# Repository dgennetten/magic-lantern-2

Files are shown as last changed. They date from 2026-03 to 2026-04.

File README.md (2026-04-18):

# Modular Projection Lantern Generator

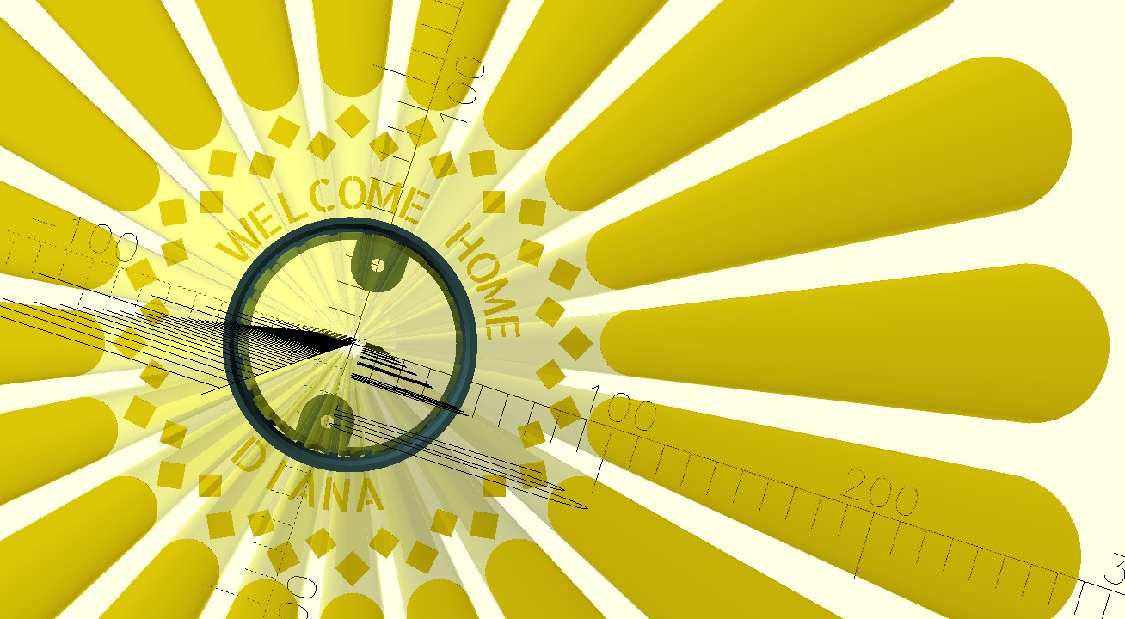
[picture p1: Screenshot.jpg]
CAD illustration


A parametric OpenSCAD project for generating 3D-printable projection lanterns. This generator calculates the precise extrusion angles required to cast undistorted 2D patterns, shapes, and text onto a floor or surface from an elevated point light source.

## OpenSCAD files

| File | Use |
|---|-----|
| **`magicLantern2.scad`** | **Recommended.** Physical settings and render mode at the top; the cutout stack is a single list, `pattern_spec`, built with `layer_*()` helpers. |
| `magicLantern.scad` | Original layout: customize by adding or editing calls inside the `all_2d_patterns()` module. |
| `magicLanternJadeJulian.scad` | Named variant of the original pattern (same `all_2d_patterns()` style). |

Place `AllertaStencil-Regular.ttf` next to whichever `.scad` file you open (see Prerequisites).

## Features

* **Parametric LED mounting:** Adjust variables to friction-fit a LED puck or fixture. Search for “Solar Light Replacement Top 4 Pack (Top Size 3.15 inch, Bottom Size 2.83 inch)” on Amazon as one example.
* **Distortion-corrected projection:** Dynamic scaling keeps patterns farther from the axis visually consistent.
* **Render modes**
  * **`PATTERNS`:** Stack of text, geometry, and rays (in v2, defined in `pattern_spec`).
  * **`SVG`:** Extrude a vector file.
  * **`CAL`:** Shortened body plus a dot spiral to check projection.
* **Mounting tabs** at the base for ceiling or bracket attachment.

## Prerequisites

1. **OpenSCAD:** [openscad.org](https://openscad.org/). For best results, use a recent or nightly build rather than only the 2021 “current” release if you hit quirks.
2. **Allerta Stencil font:** In `PATTERNS` mode, text uses this font so cutouts stay printable (fewer floating islands).
   * Download `AllertaStencil-Regular.ttf` and put it in the same folder as the `.scad` you are editing.
   * The script uses the logical name `"Allerta Stencil"`. Install the font on the system or rely on the local `use <…ttf>` path.

## Quick start

### 1. Configure the light and cylinder

Open **`magicLantern2.scad`** (or your chosen file). Under **Lantern & LED (physical)**, set:

* `light_height` — vertical reference from the bottom of the lantern (floor projection plane, z = 0). Meaning is controlled by `light_height_is_to_rim` (in `magicLantern2.scad` / `magicLantern3.scad`):
  * **`light_height_is_to_rim = false` (default):** `light_height` is floor → **LED emit plane**. The outside rim is `light_height + led_recess`. Changing `led_recess` only deepens the pocket above the LED; projection math uses `light_height` only.
  * **`light_height_is_to_rim = true`:** `light_height` is floor → **outside rim**. The LED emit plane is `light_height - led_recess`, and that value drives projection (`get_floor_r`, taper extrusion, ray preview).
* `cyl_radius`, `wall_thickness` — shell size.
* `led_diameter`, `led_recess`, `tolerance` — friction fit for the puck (`led_recess` = depth of the pocket from the rim toward the LED).

### 2. Choose render mode

Under **What to render on the floor plane**, set `render_mode`:

* `"PATTERNS"` — uses `pattern_spec` (v2) or `all_2d_patterns()` (original files).
* `"SVG"` — set `svg_filename`, `svg_scale`, and offsets.
* `"CAL"` — calibration geometry and shortened cylinder.

### 3. Customize patterns (`magicLantern2.scad`)

Edit the **`pattern_spec`** list: each entry is one `layer_*()` call. Reorder the list to change draw order; duplicate or remove lines to adjust the design.

**Layer builders** (arguments mirror the underlying `project_*` modules):

| Helper | Role |
|---|---|
| `layer_text(distance, msg, …)` | Ring of characters; optional `t_size`, `kerning_deg`, `phase_shift`, `location` (`"top"` / `"bottom"`). |
| `layer_polygon(distance, vertex, …)` | Repeating polygons; optional `rot`, `n`, `duty`, `phase_shift`. |
| `layer_circles(distance, n, …)` | Repeating circles; optional `duty`, `phase_shift`. |
| `layer_rays(distance, bar_h, n, …)` | Wedges; optional `duty`, `phase_shift`. |

**`distance`** — vertical position of the cut on the wall (smaller = closer to the light = projects farther out on the floor).

**`phase_shift`** — ring rotation, in steps of one angular segment: for rays, circles, and polygons it is `phase_shift × (360/n)` degrees. For text it is `phase_shift × kerning_deg`.

The file defines **`_ray_bar_w`** like the original `width_24` helper; use it in `layer_rays(…, bar_h = _ray_bar_w * 4, …)` when you want bar height tied to cylinder arc width.

If you need a new primitive, add a **`layer_*`** function that returns a tagged list, handle it in **`apply_pattern_entry`**, and append to **`pattern_spec`**. The **`project_*`** modules remain the implementation for each shape type.

### 3b. Original files (`magicLantern.scad`, etc.)

In those files, open the **`all_2d_patterns()`** module and add or change **`project_text`**, **`project_polygon`**, **`project_circles`**, and **`project_rays`** calls. Parameters are the same as in the table above, exposed on the `project_*` modules:

**`project_text()`** — Arc centered at **12 o’clock** (top) or **6 o’clock** (bottom) when `phase_shift` is `0`. Two calls with `location = "top"` and `"bottom"` give two opposite arcs.

* **`msg`** — string to project.
* **`t_size`**, **`kerning_deg`**, **`phase_shift`**, **`location`** — as above; **`f_name`** overrides the global font for that ring.

**`project_polygon()`** — **`vertex`** (e.g. `4` for diamonds), **`rot`**, **`n`**, **`duty`**.

**`project_circles()`** — **`n`**, **`duty`**.

**`project_rays()`** — **`bar_h`** (vertical extent of the cut on the wall), **`n`**, **`duty`**.

### 4. Preview and export

1. **F5** — preview.
2. Set **`show_light_rays = false`** before export so visualization geometry is not merged into the mesh.
3. **F6** — full render.
4. **File → Export** as STL (or 3MF).

## Slicing and printing

* **Resolution:** `$fn = 120` for smooth cylinders; high-res meshes work well in slicers such as OrcaSlicer (seam painting along a tab edge can hide the Z-seam).
* **Material:** PLA is fine for tests and `CAL`. If the LED runs warm, PETG reduces long-term warping.
* **Hardware:** Tested on enclosed Core-XY machines (e.g. FlashForge AD5X).
* **Orientation:** Print vertically, LED cavity up; typical pattern cutouts need no supports.

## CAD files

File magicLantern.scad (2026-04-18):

// ==========================================
// MODULAR PROJECTION LANTERN GENERATOR
// ==========================================

// 1. Global Lantern Parameters
light_height = 90;
// Meaning depends on `light_height_is_to_rim` (floor at z = 0)
cyl_radius = 40;
// Outer radius of the lantern cylinder
wall_thickness = 2;      // Thickness of the cylinder wall
font_name = "Allerta Stencil"; 
// Windows default Stencil font
use <AllertaStencil-Regular.ttf>;
$fn = 120;               // Smoothness of 3D curves

// 2. LED Mounting Parameters
led_diameter = 72.5;
// Outer diameter of physical LED light fixture
led_recess = 24;
// Pocket depth from outside rim down toward the LED (how far the emit plane sits below the rim)
tolerance = 0.25;
// Clearance for a snug friction fit

// false: `light_height` = floor → LED (rim = light_height + led_recess). true: `light_height` = floor → rim, LED = light_height - led_recess
light_height_is_to_rim = false;

function projection_led_height() = light_height_is_to_rim ? (light_height - led_recess) : light_height;
function lantern_rim_height() = light_height_is_to_rim ? light_height : (light_height + led_recess);

// 3. Visualization Toggle
show_light_rays = true;
// MUST BE FALSE for final F6 mesh export!

// ==========================================
// 4. RENDER MODE & SVG CONTROLS
// ==========================================
// Select: "PATTERNS", "SVG", or "CAL"
render_mode = "PATTERNS";
svg_filename = "my_pattern.svg"; 
svg_scale = 1.0;         
svg_x_offset = 0;        
svg_y_offset = 0;
// Pre-calculated physical arc widths for the ray cutouts
width_24 = (2 * PI * cyl_radius / 24) * 0.5;
width_12 = (2 * PI * cyl_radius / 12) * 0.5;
// REFACTORED: Calculates floor radius based on distance down from the LED
function get_floor_r(distance) = (projection_led_height() * cyl_radius) / distance;

// ==========================================
// 2D FLOOR PATTERN MODULES
// ==========================================
module project_text(distance, msg, t_size=8, kerning_deg=12, f_name=font_name, phase_shift=0, location="top") {
    floor_r = get_floor_r(distance);
    chars = len(msg);
    total_angle = (chars - 1) * kerning_deg;
    // Half-span so the midpoint between first and last glyph sits at noon (top) or 6 o'clock (bottom).
    start_angle = total_angle / 2;
    bottom = (location == "bottom");
    center_angle = bottom ? 180 : 0;
    // phase_shift=0: arc centered on center_angle. Nonzero: extra rotation in kerning_deg steps.
    angle_offset = kerning_deg * phase_shift;
    for (i = [0 : chars - 1]) {
        a = bottom
            ? (center_angle - start_angle + i * kerning_deg + angle_offset)
            : (center_angle + start_angle - i * kerning_deg + angle_offset);
        rotate(a)
            translate([0, floor_r])
                rotate(bottom ? 180 : 0)
                    text(msg[i], size=t_size, font=f_name, halign="center", valign="center");
    }
}

module project_rays(distance, bar_h, n, duty=0.5, phase_shift=0) {
    // A smaller distance is closer to the light source (higher up the cylinder)
    dist_top = distance - (bar_h / 2);
    dist_bottom = distance + (bar_h / 2);
    
    // The top of the ray projects further out onto the floor than the bottom
    r_outer = get_floor_r(dist_top);
    r_inner = get_floor_r(dist_bottom);
    
    angle_step = 360 / n;
    wedge_angle = angle_step * duty;
    angle_offset = angle_step * phase_shift;
    for (i = [0 : n - 1]) {
        rotate(i * angle_step + angle_offset)
            polygon([
                [ r_inner * tan(wedge_angle/2), r_inner ],
                [ r_outer * tan(wedge_angle/2), r_outer ],
                [-r_outer * tan(wedge_angle/2), r_outer ],
                [-r_inner * tan(wedge_angle/2), r_inner ]
            ]);
    }
}

module project_circles(distance, n, duty=0.5, phase_shift=0) {
    floor_r = get_floor_r(distance);
    angle_step = 360 / n;
    c_r = floor_r * sin((angle_step * duty) / 2);
    angle_offset = angle_step * phase_shift;
    for (i = [0 : n - 1]) {
        rotate(i * angle_step + angle_offset)
            translate([0, floor_r])
                circle(r = c_r);
    }
}

module project_polygon(distance, vertex, rot=0, n=24, duty=0.5, phase_shift=0) {
    floor_r = get_floor_r(distance);
    angle_step = 360 / n;
    p_r = floor_r * sin((angle_step * duty) / 2);
    angle_offset = angle_step * phase_shift;
    for (i = [0 : n - 1]) {
        rotate(i * angle_step + angle_offset)
            translate([0, floor_r])
                // +90 forces 1st vertex to 12 o'clock.
                // -rot applies clockwise offset.
                rotate(90 - rot)
                    circle(r = p_r, $fn = vertex);
    }
}

module project_cal_spiral(start_r=75, end_r=300, dots=37, dot_size=5) {
    // 37 dots guarantees exactly one dot every 10 degrees for a full 360 turn
    for (i = [0 : dots - 1]) {
        angle = i * (360 / (dots - 1));
        floor_r = start_r + i * ((end_r - start_r) / (dots - 1));
        rotate(angle)
            translate([0, floor_r])
                circle(d = dot_size);
    }
}

module all_2d_patterns() {
    if (render_mode == "PATTERNS") {
        // Distances recalculated from 130mm light_height to maintain exact visual placement
        project_text(distance = 65, msg = "WELCOME HOME", t_size = 12, kerning_deg = 12, location = "top");
        project_text(distance = 65, msg = "DIANA", t_size = 12, kerning_deg = 12, location = "bottom");
        // Diamonds (vertex=4, rot=0)
        project_polygon(distance = 44, vertex = 4, rot = 0, n = 20, duty = 0.5);
        // Diamonds (vertex=4, rot=0, phase_shift=.5)
        project_polygon(distance = 49, vertex = 4, rot = 0, n = 20, duty = 0.5, phase_shift = 0.5);
        project_circles(distance = 35, n = 20, duty = 0.75);
        project_rays(distance = 25, bar_h = width_24 * 4, n = 20, duty = 0.75);
        project_circles(distance = 14.5, n = 20, duty = 0.75);

    } else if (render_mode == "SVG") {
        translate([svg_x_offset, svg_y_offset])
            scale([svg_scale, svg_scale])
                import(svg_filename);
    } else if (render_mode == "CAL") {
        project_cal_spiral();
    } else {
        echo("ERROR: render_mode must be 'PATTERNS', 'SVG', or 'CAL'");
    }
}

// ==========================================
// 3D LANTERN COMPONENTS
// ==========================================
module lantern_body() {
    fit_radius = (led_diameter / 2) + tolerance;
    // LED cavity starts slightly below light_height to avoid a coplanar face with the bore (preview/STL).
    merge_eps = 0.05;
    
    led_z = projection_led_height();
    total_height = lantern_rim_height();
    // Auto-shorten the cylinder by 50mm if doing a Calibration print
    cyl_bottom_z = (render_mode == "CAL") ? 50 : 0;

    // Scale math to avoid the tip singularity during extrusion
    extrude_h = led_z - 5;
    extrude_scale = (led_z - extrude_h) / led_z;
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

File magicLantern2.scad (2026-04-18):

// ==========================================
// Modular projection lantern — data-first layout
// Compose cutout layers in pattern_spec (top of file, after a short helper block).
// ==========================================

// ---------------------------------------------------------------------------
// 1. Lantern & LED (physical)
// ---------------------------------------------------------------------------
light_height = 90;           // See `light_height_is_to_rim` below
cyl_radius = 40;
wall_thickness = 2;
//font_name = "Boston Traffic";
//use <boston_traffic.ttf>;
font_name = "Allerta Stencil";
use <AllertaStencil-Regular.ttf>;
$fn = 120;

led_diameter = 72.5;
led_recess = 24;             // Pocket depth from outside rim down toward the LED
tolerance = 0.25;

// How `light_height` is measured (floor at z = 0):
// - false (default): floor → LED emit plane. Rim height = light_height + led_recess. Recess only sizes the lid.
// - true: floor → outside rim. LED emit plane = light_height - led_recess (recess enters projection math).
light_height_is_to_rim = false;

function projection_led_height() = light_height_is_to_rim ? (light_height - led_recess) : light_height;
function lantern_rim_height() = light_height_is_to_rim ? light_height : (light_height + led_recess);

// Mount style: "tabs" (two interior screw tabs) or "flange" (full disc, 1" centre hole)
mount_style = "flange";

// ---------------------------------------------------------------------------
// 2. What to render on the floor plane
//    "PATTERNS" → pattern_spec  |  "SVG" → import  |  "CAL" → calibration spiral
// ---------------------------------------------------------------------------
render_mode = "PATTERNS";
svg_filename = "my_pattern.svg";
svg_scale = 1.0;
svg_x_offset = 0;
svg_y_offset = 0;

// ---------------------------------------------------------------------------
// 3. Declarative layer builders (needed before pattern_spec in OpenSCAD)
// ---------------------------------------------------------------------------
function layer_text(distance, msg, t_size = 8, kerning_deg = 12, phase_shift = 0, location = "top") =
    ["text", distance, msg, t_size, kerning_deg, phase_shift, location];

function layer_rays(distance, bar_h, n, duty = 0.5, phase_shift = 0, count = 0) =
    ["rays", distance, bar_h, n, duty, phase_shift, count];

function layer_circles(distance, n, duty = 0.5, phase_shift = 0, count = 0) =
    ["circles", distance, n, duty, phase_shift, count];

function layer_polygon(distance, vertex, rot = 0, n = 24, duty = 0.5, phase_shift = 0, count = 0) =
    ["polygon", distance, vertex, rot, n, duty, phase_shift, count];

// ---------------------------------------------------------------------------
// 4. Pattern stack — main customization: reorder or edit entries here
// ---------------------------------------------------------------------------
_ray_bar_w = (2 * PI * cyl_radius / 24) * 0.5;

pattern_spec = [
    layer_text(65, "WELCOME HOME", t_size = 12, kerning_deg = 12, location = "top"),
    layer_text(65, "DIANA", t_size = 12, kerning_deg = 12, location = "bottom"),
    layer_polygon(44, vertex = 4, rot = 0, n = 20, duty = 0.5, phase_shift = 0.5),
    layer_polygon(49, vertex = 4, rot = 0, n = 20, duty = 0.5),
    layer_circles(35, n = 20, duty = 0.75, count = 10),
    layer_rays(25, bar_h = _ray_bar_w * 4, n = 20, duty = 0.75, count = 10),
    layer_circles(14.5, n = 20, duty = 0.75, count = 10),
];

// ---------------------------------------------------------------------------
// 5. Preview
// ---------------------------------------------------------------------------
show_light_rays = true;   // set false for F6 export

// ---------------------------------------------------------------------------
// 6. Projection math & 2D primitives
// ---------------------------------------------------------------------------
function get_floor_r(distance) = (projection_led_height() * cyl_radius) / distance;

module project_text(distance, msg, t_size = 8, kerning_deg = 12, f_name = font_name, phase_shift = 0, location = "top") {
    floor_r = get_floor_r(distance);
    chars = len(msg);
    total_angle = (chars - 1) * kerning_deg;
    start_angle = total_angle / 2;
    bottom = (location == "bottom");
    center_angle = bottom ? 180 : 0;
    angle_offset = kerning_deg * phase_shift;
    for (i = [0 : chars - 1]) {
        a = bottom
            ? (center_angle - start_angle + i * kerning_deg + angle_offset)
            : (center_angle + start_angle - i * kerning_deg + angle_offset);
        rotate(a)
            translate([0, floor_r])
                rotate(bottom ? 180 : 0)
                    text(msg[i], size = t_size, font = f_name, halign = "center", valign = "center");
    }
}

module project_rays(distance, bar_h, n, duty = 0.5, phase_shift = 0, count = 0) {
    dist_top = distance - (bar_h / 2);
    dist_bottom = distance + (bar_h / 2);
    r_outer = get_floor_r(dist_top);
    r_inner = get_floor_r(dist_bottom);
    angle_step = 360 / n;
    wedge_angle = angle_step * duty;
    angle_offset = angle_step * phase_shift;
    actual_count = (count > 0 && count <= n) ? count : n;
    rot_sign = (count > 0) ? -1 : 1;
    for (i = [0 : actual_count - 1]) {
        rotate(rot_sign * i * angle_step + angle_offset)
            polygon([
                [ r_inner * tan(wedge_angle / 2), r_inner ],
                [ r_outer * tan(wedge_angle / 2), r_outer ],
                [-r_outer * tan(wedge_angle / 2), r_outer ],
                [-r_inner * tan(wedge_angle / 2), r_inner ]
            ]);
    }
}

module project_circles(distance, n, duty = 0.5, phase_shift = 0, count = 0) {
    floor_r = get_floor_r(distance);
    angle_step = 360 / n;
    c_r = floor_r * sin((angle_step * duty) / 2);
    angle_offset = angle_step * phase_shift;
    actual_count = (count > 0 && count <= n) ? count : n;
    rot_sign = (count > 0) ? -1 : 1;
    for (i = [0 : actual_count - 1]) {
        rotate(rot_sign * i * angle_step + angle_offset)
            translate([0, floor_r])
                circle(r = c_r);
    }
}

module project_polygon(distance, vertex, rot = 0, n = 24, duty = 0.5, phase_shift = 0, count = 0) {
    floor_r = get_floor_r(distance);
    angle_step = 360 / n;
    p_r = floor_r * sin((angle_step * duty) / 2);
    angle_offset = angle_step * phase_shift;
    actual_count = (count > 0 && count <= n) ? count : n;
    rot_sign = (count > 0) ? -1 : 1;
    for (i = [0 : actual_count - 1]) {
        rotate(rot_sign * i * angle_step + angle_offset)
            translate([0, floor_r])
                rotate(90 - rot)
                    circle(r = p_r, $fn = vertex);
    }
}

module project_cal_spiral(start_r = 75, end_r = 300, dots = 37, dot_size = 5) {
    for (i = [0 : dots - 1]) {
        angle = i * (360 / (dots - 1));
        floor_r = start_r + i * ((end_r - start_r) / (dots - 1));
        rotate(angle)
            translate([0, floor_r])
                circle(d = dot_size);
    }
}

module apply_pattern_entry(entry) {
    kind = entry[0];
    if (kind == "text") {
        project_text(
            distance = entry[1],
            msg = entry[2],
            t_size = entry[3],
            kerning_deg = entry[4],
            phase_shift = entry[5],
            location = entry[6]
        );
    } else if (kind == "rays") {
        project_rays(
            distance = entry[1],
            bar_h = entry[2],
            n = entry[3],
            duty = entry[4],
            phase_shift = entry[5],
            count = entry[6]
        );
    } else if (kind == "circles") {
        project_circles(
            distance = entry[1],
            n = entry[2],
            duty = entry[3],
            phase_shift = entry[4],
            count = entry[5]
        );
    } else if (kind == "polygon") {
        project_polygon(
            distance = entry[1],
            vertex = entry[2],
            rot = entry[3],
            n = entry[4],
            duty = entry[5],
            phase_shift = entry[6],
            count = entry[7]
        );
    } else {
        echo("Unknown pattern entry kind: ", kind);
    }
}

module all_2d_patterns() {
    if (render_mode == "PATTERNS") {
        for (entry = pattern_spec)
            apply_pattern_entry(entry);
    } else if (render_mode == "SVG") {
        translate([svg_x_offset, svg_y_offset])
            scale([svg_scale, svg_scale])
                import(svg_filename);
    } else if (render_mode == "CAL") {
        project_cal_spiral();
    } else {
        echo("ERROR: render_mode must be 'PATTERNS', 'SVG', or 'CAL'");
    }
}
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

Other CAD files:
magicLantern3.scad
magicLantern4.scad
magicLanternJadeJulian.scad

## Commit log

2026-03-11 Update magicLantern.scad: Adjusted LED parameters, enabled light ray visualization, and modified render mode to support patterns. Refined lantern body structure for improved LED fitting and extrusion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
    [magicLantern.scad]
2026-03-11 Refactor magicLantern.scad: Enhanced calibration mode functionality, optimized spiral projection rendering, and fine-tuned lantern body dimensions for better assembly and light distribution.
2026-03-12 Refactor magicLantern.scad: Adjusted light height for improved projection accuracy, changed render mode to "PATTERNS", and refactored functions for better parameter handling. Enhanced text projection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
    [magicLantern.scad]
2026-03-12 Refactor magicLantern.scad: Updated font to "Allerta Stencil", enabled light ray visualization, and refined text projection parameters. Adjusted comments for clarity and removed unused SVG file.
    [magicLantern.scad]
2026-03-12 Update README with LED puck link
    Added a link to the LED puck or light source in the features section.
2026-03-12 Update README with LED puck product reference
    Added a specific product reference for LED mounting.
2026-03-21 Remove the unneeded flange
    [magicLantern.scad]
2026-03-21 Cleaned up cylinder interior where previous flange was
    [magicLantern.scad, magicLanternJadeJulian.scad]
2026-03-21 same fix to J&J
    [magicLanternJadeJulian.scad]
2026-03-22 Update light height and adjust text and pattern distances in magicLanternJadeJulian.scad for improved visual placement. Added new facets in magicLanternJadeJulian.stl to enhance model detail.
    [magicLanternJadeJulian.scad]
2026-03-23 Much improved version 2. New "pattern_spec"
    [magicLantern2.scad]
2026-04-08 Refactor magicLanternJadeJulian.scad to enhance text alignment and update pattern specifications for improved visual consistency. Adjusted parameters for better model detail in magicLanternJadeJulian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
2026-04-15 Enhance magicLantern2.scad by introducing a new mount style option ("flange") for improved design flexibility. Updated pattern specifications and refined cylinder construction for better structural i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
    [magicLantern2.scad]
2026-04-15 Refactor magicLantern2.scad to add a 'count' parameter to layer functions and project modules, enhancing control over the number of elements rendered. Updated pattern specifications to utilize the ne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
    [magicLantern2.scad]
2026-04-18 Refactor projection calculations in magicLantern.scad and related files to incorporate `light_height_is_to_rim` parameter, enhancing clarity and accuracy in light projection. Update documentation and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
    [magicLantern.scad, magicLantern2.scad, magicLantern3.scad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]
2026-04-27 Update LED inner diameter and refine text layer specifications in magicLantern3.scad for improved design accuracy. Adjusted ray and polygon layers for enhanced visual effects in the model. Updated ma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
    [magicLantern3.scad, magicLantern4.scad]
2026-04-27 Change mount style from "flange" to "tabs" in magicLantern4.scad to enhance design flexibility and accommodate new mounting requirements.
    [magicLantern4.scad]
